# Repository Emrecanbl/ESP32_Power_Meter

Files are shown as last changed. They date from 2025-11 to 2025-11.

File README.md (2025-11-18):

# ESP32-S3 Power Meter (INA3221 ·  TFT · Qt Ui · SQLlite data base)

An ESP32-S3–based **three-channel power meter** built around INA3221. One channel supports **USB-C pass-through** so you can measure power flowing from **USB-C IN → USB-C OUT**; **CC pins are tied** for basic PD trigger behavior (power-only path).

> Firmware stack: **FreeRTOS**.
> REST/WebSocket API is **optional** (may be added later).
> Live data can be streamed over **USB-CDC**; an **optional ST7735 (160×128) SPI TFT** can show basic status (no touch).
>
> A custom **3D-printed enclosure** is planned.

---

---

## Features

* **3 measurement channels** via **INA3221**

  * Voltage (V), Current (A), Power (W), accumulated **mAh / mWh**
* **ESP32-S3** (Wi‑Fi + native USB/CDC)

  * UART header and USB device available on the board
* **USB‑C pass‑through (1 channel)**: measure power across IN → OUT

  * **CC lines tied** (basic PD role trigger; data lines not routed)
* **Optional TFT:** **ST7735 (160×128) SPI** for basic on-device status (no touch)
* **Battery**: **TP4056** Li‑ion charger + **AMS1117‑3.3** LDO
* **Enclosure**: custom **3D‑printed** case (to be published)

---

## What’s New

* Qt UI with Python and SQLite database integration

* Added boot-time Check screen: verifies Wi‑Fi link and sensor health before entering the UI.

* Check screen now shows connection status and the assigned IP address.

* Main screen updated to display the device IP for quick access to the Web UI.

* **ST7735 (160×128) screen added (no touch).**

* Energy counter buttons are active (Start/Stop/Reset)

* Sensor → UART JSON and Web UI hooked up

* 4-task FreeRTOS skeleton: sensor, screen, web, uart

## Gallery

<p align="center">
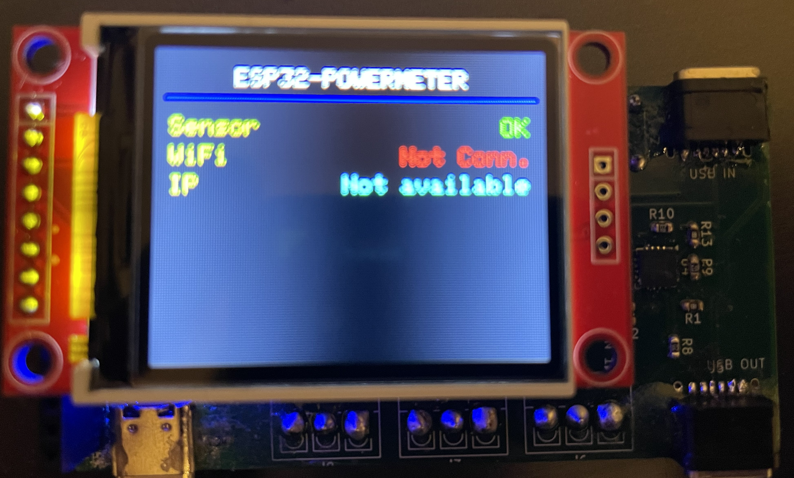
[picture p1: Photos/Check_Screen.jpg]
  &nbsp;&nbsp;
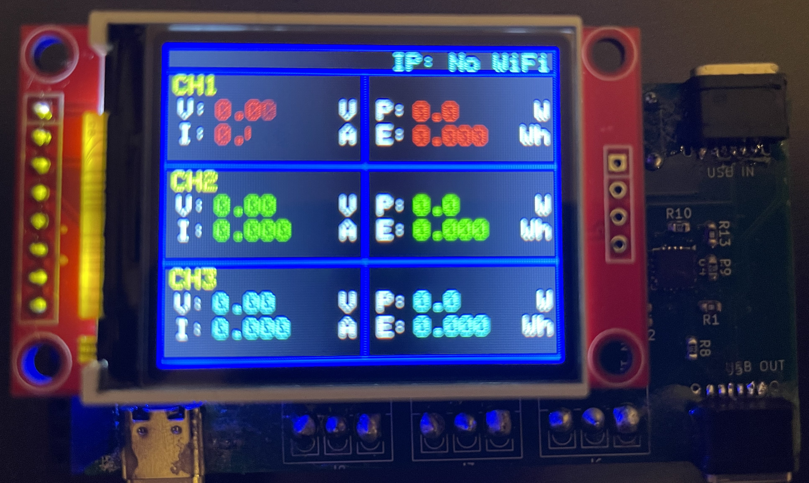
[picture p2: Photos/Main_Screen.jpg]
  <br>
  <em> First Check Screen &nbsp; | &nbsp; Main Screen </em>
</p>

<p align="center">
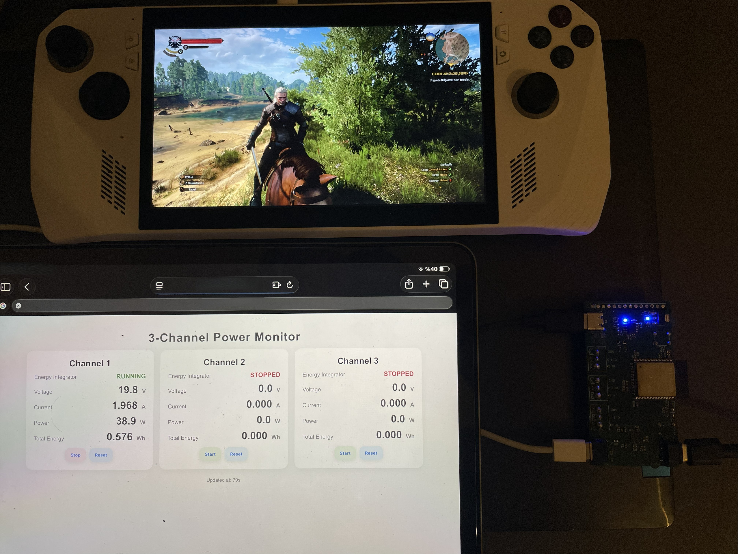
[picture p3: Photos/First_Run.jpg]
  &nbsp;&nbsp;
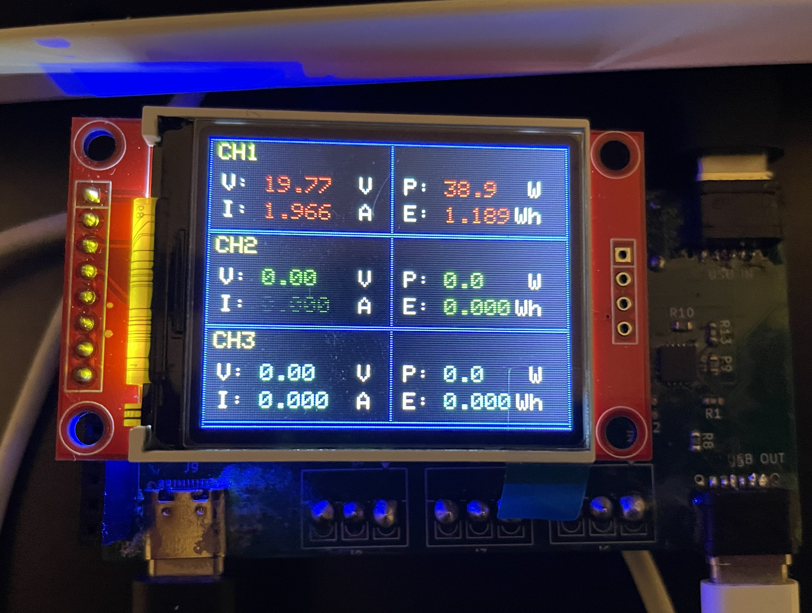
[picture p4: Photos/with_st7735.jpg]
  <br>
  <em> First Run Without Screen &nbsp; | &nbsp; With ST7735</em>
</p>

<p align="center">
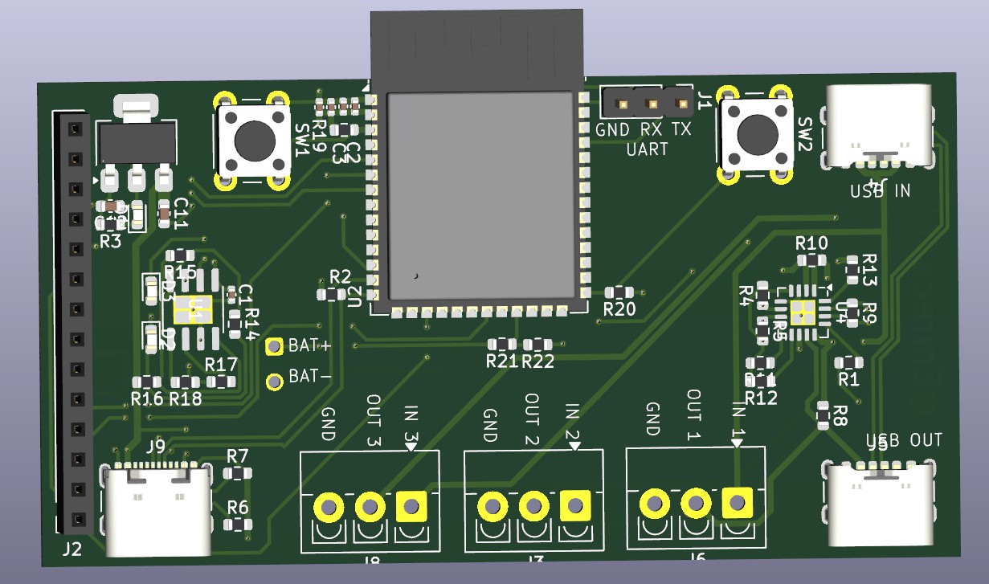
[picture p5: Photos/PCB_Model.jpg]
  &nbsp;&nbsp;
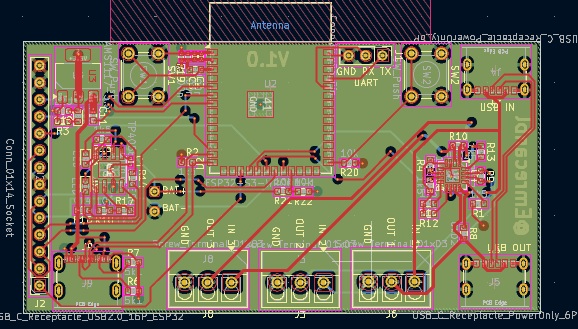
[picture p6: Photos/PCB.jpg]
  <br>
  <em>3D board render &nbsp; | &nbsp; PCB layout</em>
</p>

<p align="center">
  <!-- Add your prototype photos below when ready -->
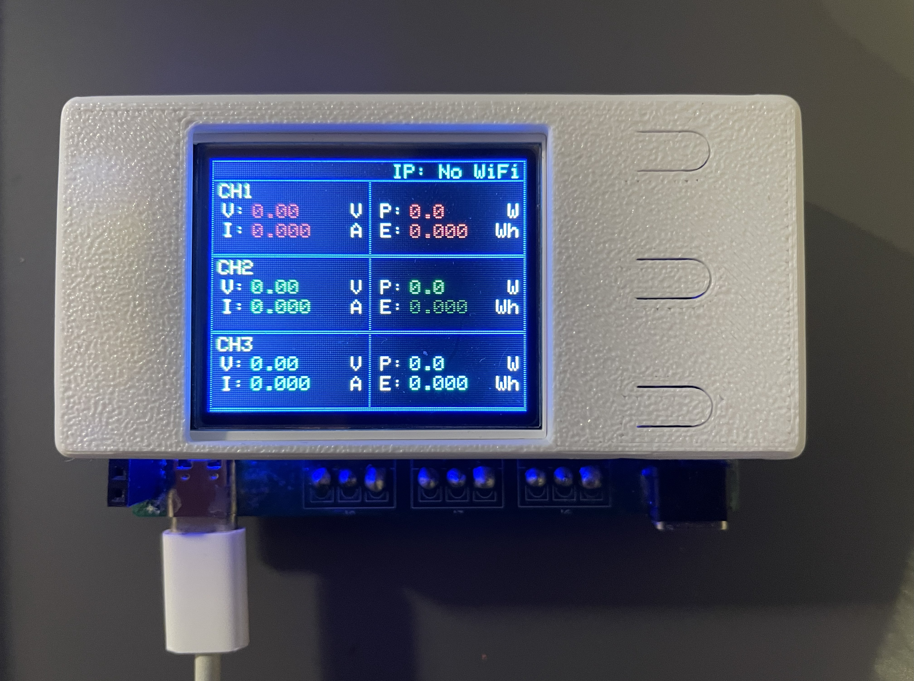
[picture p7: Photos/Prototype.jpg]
  &nbsp;&nbsp;
  <em>Prototype (front) </em>
</p>

<p align="center">
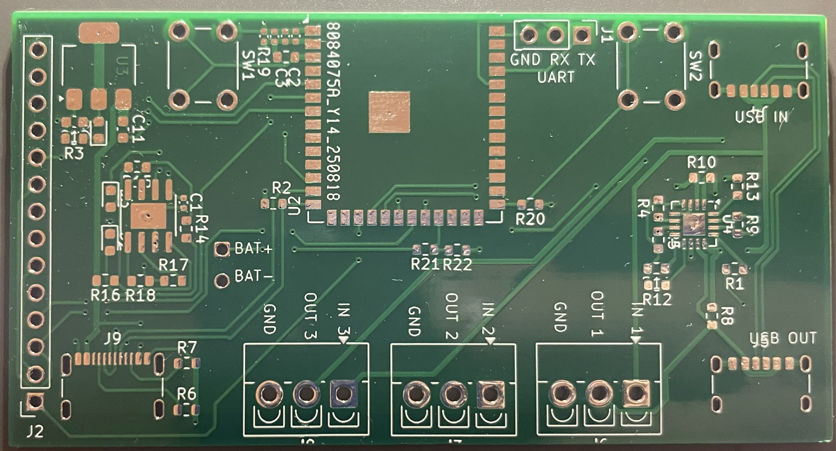
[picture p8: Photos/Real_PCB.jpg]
  <br>
  <em>Producted PCB (first article)</em>
</p>

<p align="center">
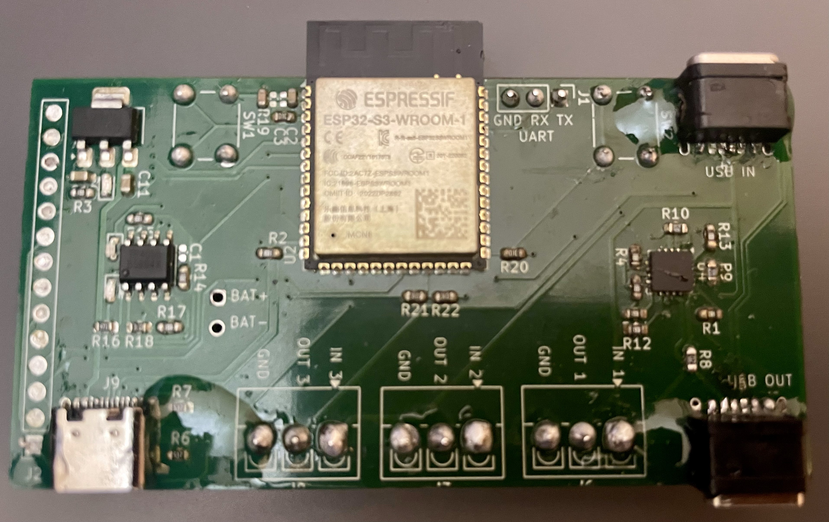
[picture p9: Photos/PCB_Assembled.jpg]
  <br>
  <em>Assembled PCB </em>
</p>

<p align="center">
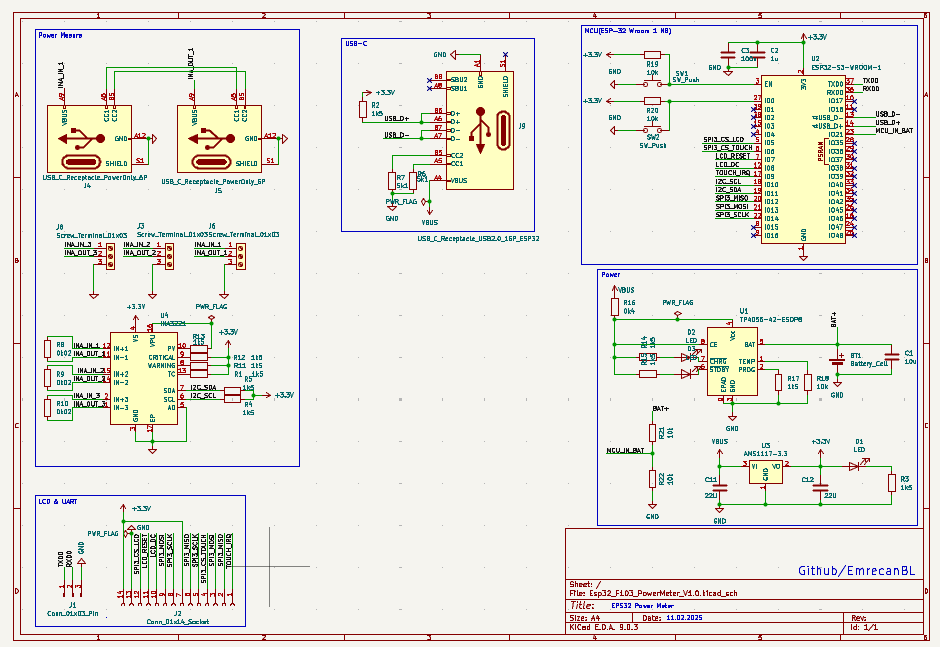
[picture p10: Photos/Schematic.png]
  <br>
  <em>Schematic (block view)</em>
</p>

<p align="center">
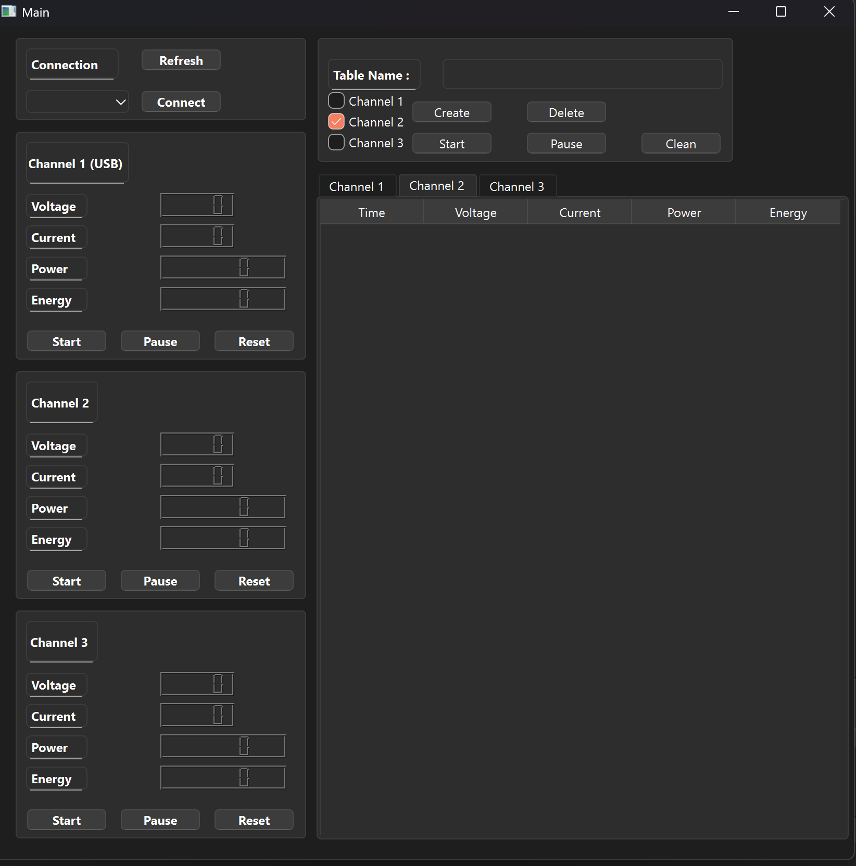
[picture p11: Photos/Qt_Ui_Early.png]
  <br>
  <em> Qt Ui </em>
</p>

## Hardware Overview

* **MCU:** ESP32‑S3 module
* **Power Monitor:** INA3221 (three shunts)
* **Optional Display:** ST7735 (160×128) over SPI (no touch)
* **Power Path:** USB‑C IN, USB‑C OUT (pass‑through on Channel 1)
* **PMICs:** TP4056 Li‑ion charger, AMS1117‑3.3 regulator
* **Connectors:** 3× screw terminals (IN/OUT/GND), UART header, 2× USB‑C

### Block Diagram

```
USB-C IN ──┐                  ┌── USB-C OUT (pass-through)
           ├─ Shunt CH1  ─────┤
IN/OUT CH2 ├─ Shunt CH2  ─────┤──> Loads
IN/OUT CH3 ├─ Shunt CH3  ─────┘
           │
        INA3221  ── I2C ── ESP32-S3 ── SPI ── ST7735 TFT (optional)
                               ├─ (Optional) Wi‑Fi HTTP/WS
                               └─ USB‑CDC / UART (streaming)
```

---

## Default Pins

| Function | ESP32‑S3 Pin |
| --- | --- |
| I2C SDA / SCL (INA3221) | GPIO __ / __ |
| TFT (ST7735) MOSI / MISO / SCK | GPIO __ / __ / __ |
| TFT CS / DC / RST | GPIO __ / __ / __ |
| UART RX / TX | GPIO __ / __ |
| USB‑CDC | Native (S3) |

---

## Firmware (planned)

* **Framework:** FreeRTOS
* **Modules:**

  * `sensor` – INA3221 sampling, filtering, mAh/mWh accumulation
  * `ui` *(optional)* – minimal status pages on **ST7735**; device can run headless
  * *(Optional)* `web` – HTTP + WebSocket for live JSON
  * `usb_stream` – ASCII/JSON streaming over USB‑CDC (no file logging)
* **Example JSON (USB/Web, if enabled):**

```json
{"ch":1,"voltage":5.08,"current":1.12,"power":5.69,"mah_total":23.4,"mwh_total":118.9,"ts":1730529652}
```

---

### Efficiency Measurement

The board can measure real conversion efficiency by comparing input and output power:

* Channels: CH1 = input (P_in), CH2 = output (P_out)
* Instantaneous: η_inst = P_out / P_in
* Averaged (stable): EMA over 1–3 s → η_avg =  P̄_out / P̄_in
* Energy-based: η_energy = ΔmWh_out / ΔmWh_in (robust against short spikes)

## Repo Layout (suggested)

```
/hardware
  schematic.pdf
  gerber/
/firmware
  /main
    board.h
    app_sensor.c
    app_ui_tft.c
    app_usb_stream.c
    (optional) app_web.c
  sdkconfig.defaults
/Photos
  PCB.jpg
  PCB_Model.jpg
  Prototype.jpg
  Prototype_Back1.jpg
  Prototype_Back2.jpg
  Real_PCB.jpg
  Schematic.png
/enclosure
  stl/  (3D-printed case files)
```

---

## Roadmap

* [ ] Bring‑up: INA3221 I2C readout
* [ ] Publish 3D‑printed enclosure (STL)
* [ ] USB‑CDC live streaming (no on‑device logs)
* [ ] Minimal on-device status (ST7735)
* [ ] Calibration UI + NVS storage
* [ ] (Optional) REST/WS endpoints

---

## Notes & Safety

* USB‑C pass‑through is **power‑only** (data lines not connected).
* CC lines support **basic PD trigger behavior**; PD profile support is **limited**.
* Verify shunt resistor wattage and temperature rise.
* Provide adequate thermal copper for **TP4056** during charging.

---

## License

MIT (to be added).

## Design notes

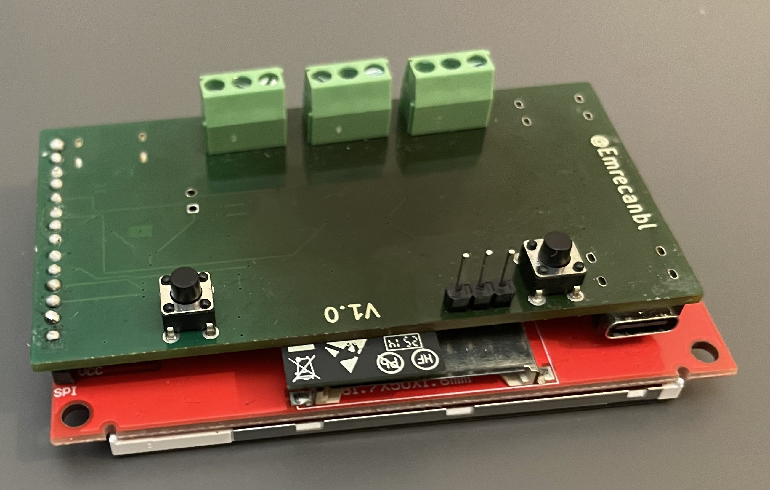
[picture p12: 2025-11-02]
Photos/Prototype_Back1.jpg

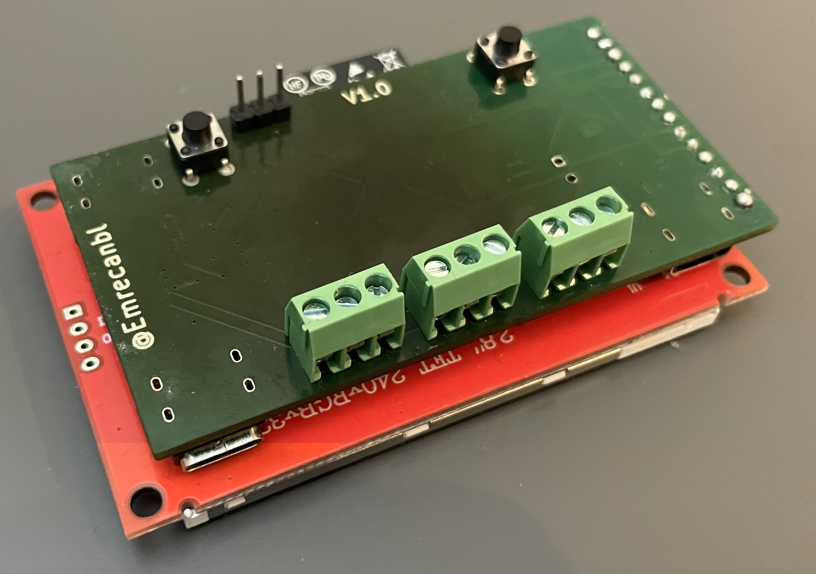
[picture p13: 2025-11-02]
Photos/Prototype_Back2.jpg

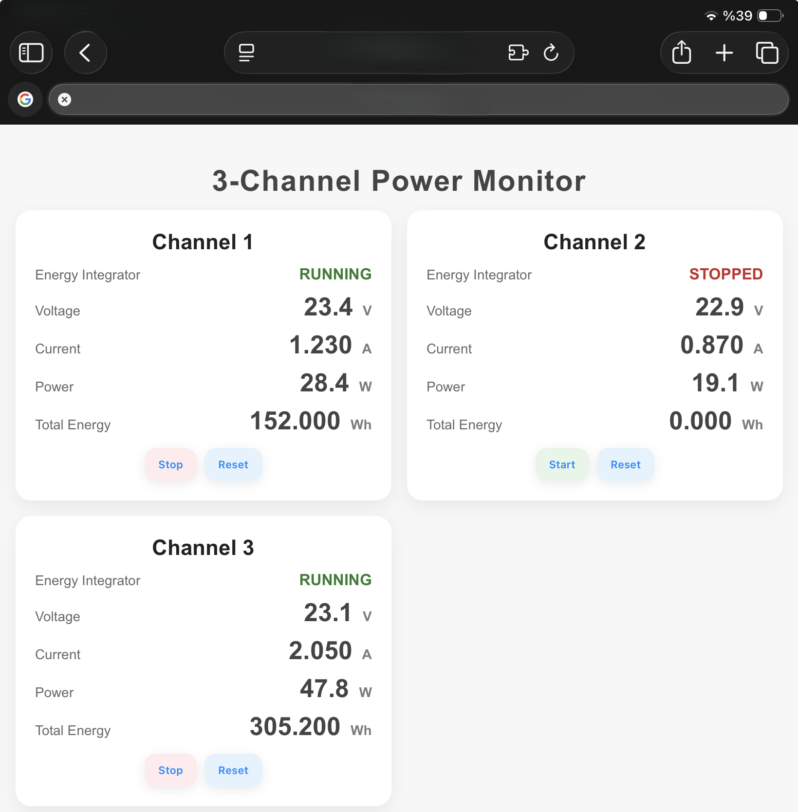
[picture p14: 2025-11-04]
Photos/WEBUI.png

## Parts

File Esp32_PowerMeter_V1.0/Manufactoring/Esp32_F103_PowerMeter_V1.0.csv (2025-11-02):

Reference | Qty | Value | DNP | Exclude from BOM | Exclude from Board | Footprint | Datasheet
BT1 | 1 | Battery_Cell |  |  |  | Connector_Molex:Molex_Micro-Fit_3.0_43045-0212_2x01_P3.00mm_Vertical | ~
C1 | 1 | 10u |  |  |  | Capacitor_SMD:C_0402_1005Metric | ~
C2 | 1 | 1u |  |  |  | Capacitor_SMD:C_0402_1005Metric | ~
C3 | 1 | 100n |  |  |  | Capacitor_SMD:C_0402_1005Metric | ~
C11,C12 | 2 | 22U |  |  |  | Capacitor_SMD:C_0603_1608Metric | ~
D1,D2,D3 | 3 | LED |  |  |  | LED_SMD:LED_0603_1608Metric | ~
J1 | 1 | Conn_01x03_Pin |  |  |  | Connector_PinHeader_2.54mm:PinHeader_1x03_P2.54mm_Vertical | ~
J2 | 1 | Conn_01x14_Socket |  |  |  | Connector_PinSocket_2.54mm:PinSocket_1x14_P2.54mm_Vertical | ~
J3,J6,J8 | 3 | Screw_Terminal_01x03 |  |  |  | TerminalBlock_4Ucon:TerminalBlock_4Ucon_1x03_P3.50mm_Vertical | ~
J4,J5 | 2 | USB_C_Receptacle_PowerOnly_6P |  |  |  | Connector_USB:USB_C_Receptacle_GCT_USB4125-xx-x_6P_TopMnt_Horizontal | https://www.usb.org/sites/default/files/documents/usb_type-c.zip
J9 | 1 | USB_C_Receptacle_USB2.0_16P_ESP32 |  |  |  | Connector_USB:USB_C_Receptacle_GCT_USB4105-xx-A_16P_TopMnt_Horizontal | https://www.usb.org/sites/default/files/documents/usb_type-c.zip
R1,R2,R3,R4,R5,R11,R12,R13,R14,R15,R17 | 11 | 1k5 |  |  |  | Resistor_SMD:R_0603_1608Metric | ~
R6,R7 | 2 | 5k1 |  |  |  | Resistor_SMD:R_0603_1608Metric | ~
R8,R9,R10 | 3 | 0k02 |  |  |  | Resistor_SMD:R_0603_1608Metric | ~
R16 | 1 | 0k4 |  |  |  | Resistor_SMD:R_0603_1608Metric | ~
R18,R19,R20,R21,R22 | 5 | 10k |  |  |  | Resistor_SMD:R_0603_1608Metric | ~
SW1,SW2 | 2 | SW_Push |  |  |  | Button_Switch_THT:SW_PUSH_6mm_H4.3mm | ~
U1 | 1 | TP4056-42-ESOP8 |  |  |  | Package_SO:SOIC-8-1EP_3.9x4.9mm_P1.27mm_EP2.41x3.3mm_ThermalVias | https://www.lcsc.com/datasheet/lcsc_datasheet_2410121619_TOPPOWER-Nanjing-Extension-Microelectronics-TP4056-42-ESOP8_C16581.pdf
U2 | 1 | ESP32-S3-WROOM-1 |  |  |  | RF_Module:ESP32-S3-WROOM-1 | https://www.espressif.com/sites/default/files/documentation/esp32-s3-wroom-1_wroom-1u_datasheet_en.pdf
U3 | 1 | AMS1117-3.3 |  |  |  | Package_TO_SOT_SMD:SOT-223-3_TabPin2 | http://www.advanced-monolithic.com/pdf/ds1117.pdf
U4 | 1 | INA3221 |  |  |  | Package_DFN_QFN:Texas_RGV0016A_VQFN-16-1EP_4x4mm_P0.65mm_EP2.1x2.1mm | http://www.ti.com/lit/ds/symlink/ina3221.pdf

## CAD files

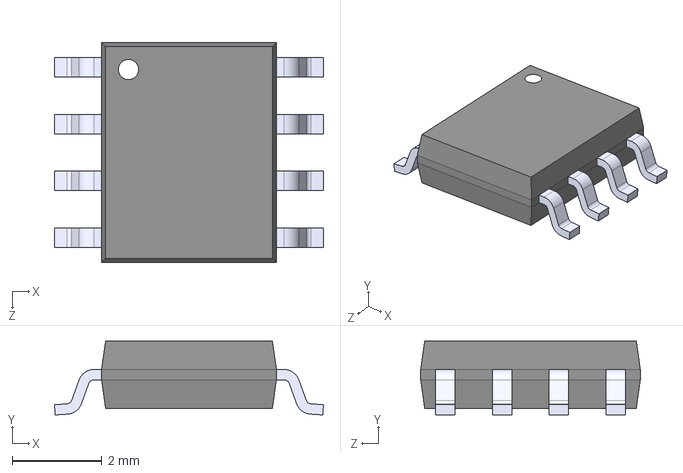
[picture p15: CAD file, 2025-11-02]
Esp32_PowerMeter_V1.0/IP5306.step
6.00 x 1.65 x 4.90 mm

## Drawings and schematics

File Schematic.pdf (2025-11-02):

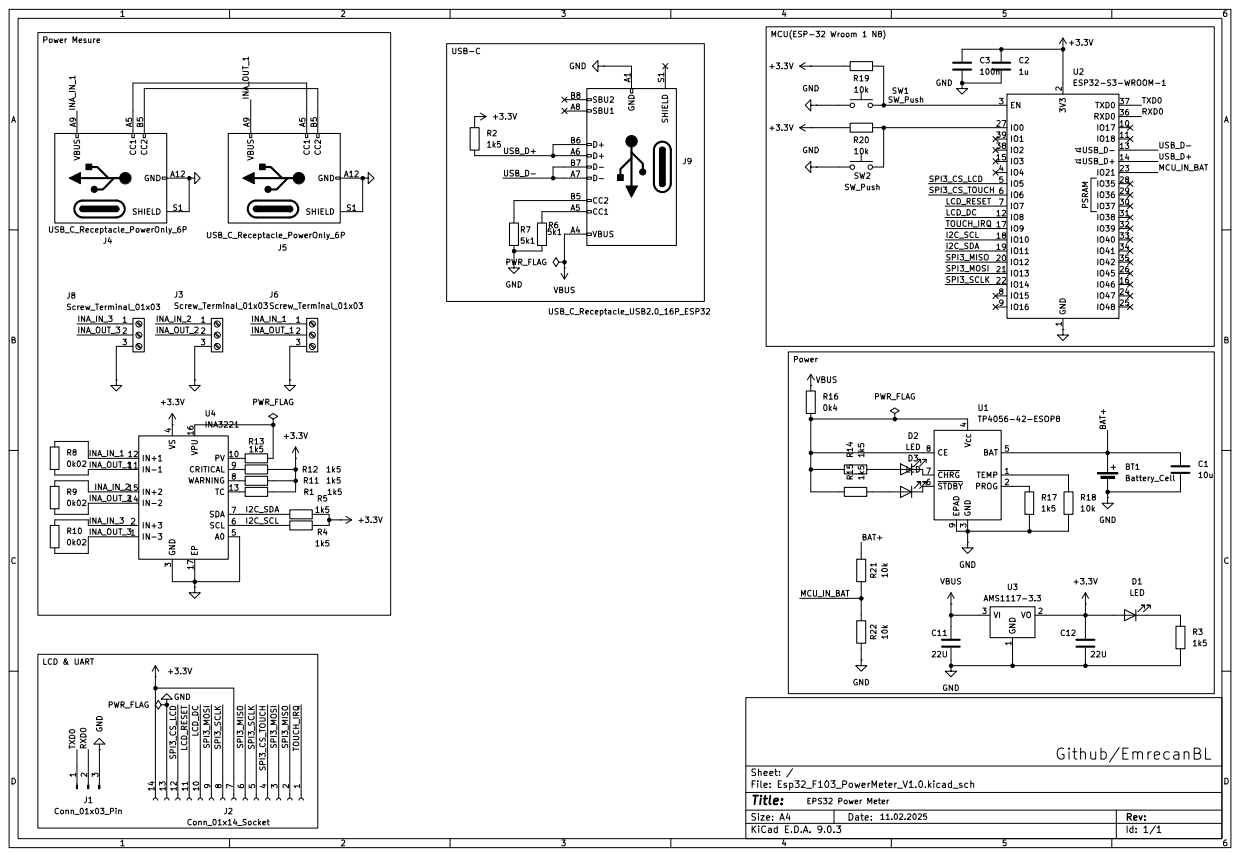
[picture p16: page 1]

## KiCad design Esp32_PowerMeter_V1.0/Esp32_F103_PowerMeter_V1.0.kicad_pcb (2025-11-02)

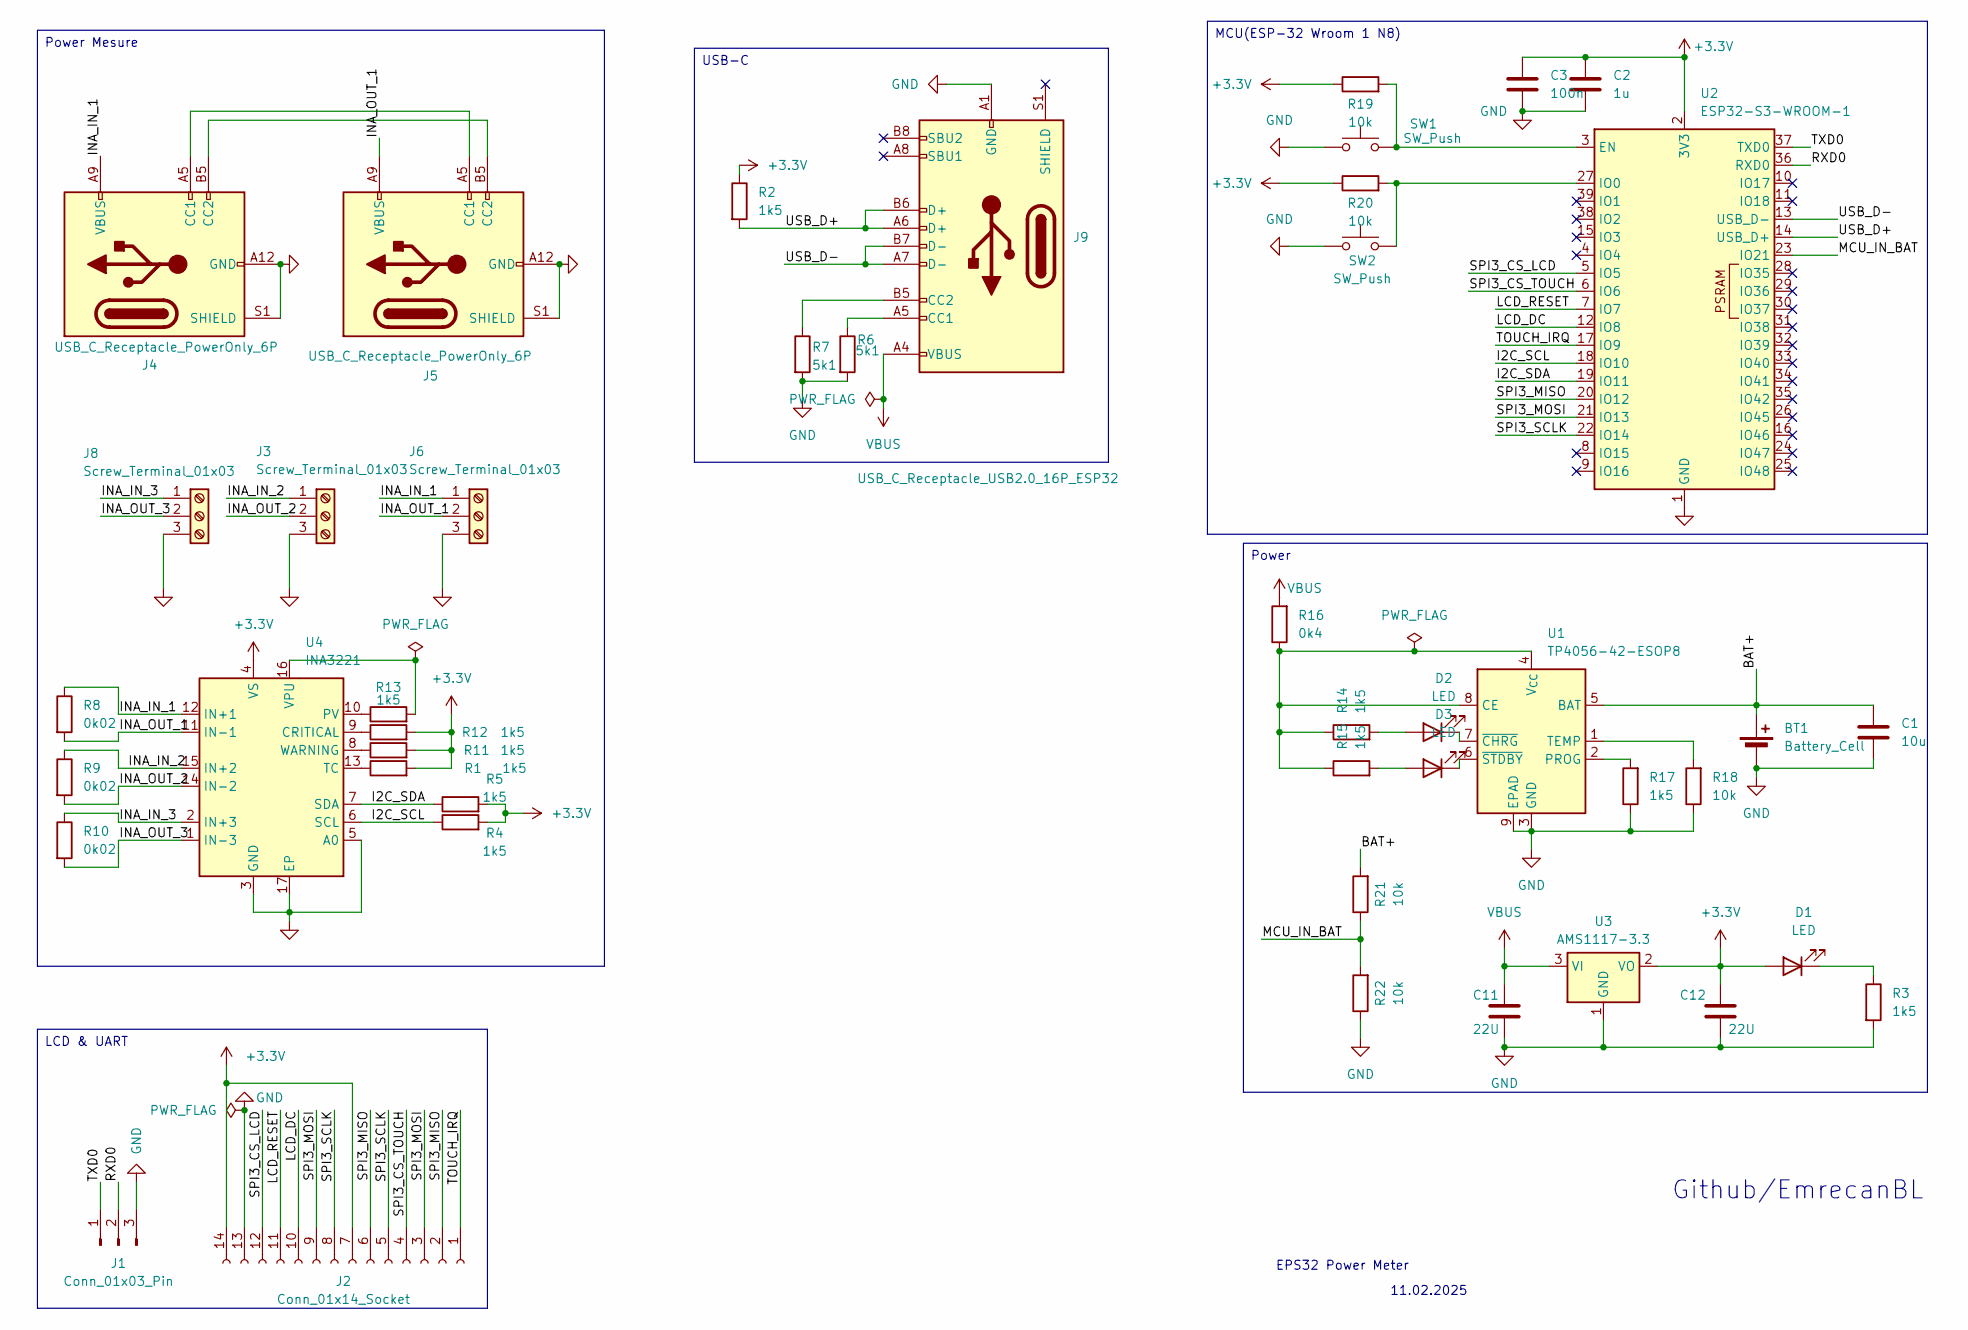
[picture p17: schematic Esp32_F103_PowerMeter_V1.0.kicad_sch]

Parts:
BT1: Battery_Cell; Molex_Micro-Fit_3.0_43045-0212_2x01_P3.00mm_Vertical
C1: 10u; C_0402_1005Metric
C2: 1u; C_0402_1005Metric
C3: 100n; C_0402_1005Metric
C11, C12: 22U; C_0603_1608Metric
D1, D2, D3: LED; LED_0603_1608Metric
J1: Conn_01x03_Pin; PinHeader_1x03_P2.54mm_Vertical
J2: Conn_01x14_Socket; PinSocket_1x14_P2.54mm_Vertical
J3, J6, J8: Screw_Terminal_01x03; TerminalBlock_4Ucon_1x03_P3.50mm_Vertical
J4, J5: USB_C_Receptacle_PowerOnly_6P; USB_C_Receptacle_GCT_USB4125-xx-x_6P_TopMnt_Horizontal
J9: USB_C_Receptacle_USB2.0_16P_ESP32; USB_C_Receptacle_GCT_USB4105-xx-A_16P_TopMnt_Horizontal
R1, R2, R3, R4, R5, R11, R12, R13, R14, R15, R17: 1k5; R_0603_1608Metric
R6, R7: 5k1; R_0603_1608Metric
R8, R9, R10: 0k02; R_0603_1608Metric
R16: 0k4; R_0603_1608Metric
R18, R19, R20, R21, R22: 10k; R_0603_1608Metric
SW1, SW2: SW_Push; SW_PUSH_6mm_H4.3mm
U1: TP4056-42-ESOP8; SOIC-8-1EP_3.9x4.9mm_P1.27mm_EP2.41x3.3mm_ThermalVias
U2: ESP32-S3-WROOM-1
U3: AMS1117-3.3; SOT-223-3_TabPin2
U4: INA3221; Texas_RGV0016A_VQFN-16-1EP_4x4mm_P0.65mm_EP2.1x2.1mm

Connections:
+3.3V: C2.1, C3.1, C12.1, D1.2 (A), J2.7, J2.14, R1.2, R2.1, R4.2, R5.2, R11.2, R12.2, R19.1, R20.1, U2.2 (3V3), U3.2 (VO), U4.4 (VS); also elsewhere on the board
/BAT+: BT1.1 (+), C1.1, R21.2, U1.5 (BAT)
/I2C_SCL: R4.1, U2.18 (IO10), U4.6 (SCL)
/I2C_SDA: R5.1, U2.19 (IO11), U4.7 (SDA)
/INA_IN_1: J4.A9 (VBUS), J4.B9 (VBUS), J6.1, R8.1, U4.12 (IN+1)
/INA_IN_2: J3.1, R9.1, U4.15 (IN+2)
/INA_IN_3: J8.1, R10.1, U4.2 (IN+3)
/INA_OUT_1: J5.A9 (VBUS), J5.B9 (VBUS), J6.2, R8.2, U4.11 (IN-1)
/INA_OUT_2: J3.2, R9.2, U4.14 (IN-2)
/INA_OUT_3: J8.2, R10.2, U4.1 (IN-3)
/LCD_DC: J2.10, U2.12 (IO8)
/LCD_RESET: J2.11, U2.7 (IO7)
/MCU_IN_BAT: R21.1, R22.2, U2.23 (IO21)
/RXD0: J1.2, U2.36 (RXD0)
/SPI3_CS_LCD: J2.12, U2.5 (IO5)
/SPI3_CS_TOUCH: J2.4, U2.6 (IO6)
/SPI3_MISO: J2.2, J2.6, U2.20 (IO12)
/SPI3_MOSI: J2.3, J2.9, U2.21 (IO13)
/SPI3_SCLK: J2.5, J2.8, U2.22 (IO14)
/TOUCH_IRQ: J2.1, U2.17 (IO9)
/TXD0: J1.1, U2.37 (TXD0)
/USB_D+: J9.A6 (D+), J9.B6 (D+), R2.2, U2.14 (USB_D+)
/USB_D-: J9.A7 (D-), J9.B7 (D-), U2.13 (USB_D-)
GND: BT1.2 (-), C1.2, C2.2, C3.2, C11.2, C12.2, J1.3, J2.13, J3.3, J4.A12 (GND), J4.B12 (GND), J4.S1 (SHIELD), J5.A12 (GND), J5.B12 (GND), J5.S1 (SHIELD), J6.3, J8.3, J9.A1 (GND), J9.A12 (GND), J9.B1 (GND), J9.B12 (GND), R3.2, R6.2, R7.2, R17.1, R18.1, R22.1, SW1.1, SW2.1, U1.3 (GND), U1.9 (EPAD), U2.1 (GND), U2.40 (GND), U2.41 (GND), U3.1 (GND), U4.3 (GND), U4.5 (A0), U4.17 (EP); also elsewhere on the board
unnamed: D1.1 (K), R3.1
unnamed: D2.2 (A), R14.2
unnamed: D2.1 (K), U1.7 (~CHRG)
unnamed: D3.2 (A), R15.2
unnamed: D3.1 (K), U1.6 (~STDBY)
unnamed: J4.A5 (CC1), J5.A5 (CC1)
unnamed: J4.B5 (CC2), J5.B5 (CC2)
unnamed: J9.A5 (CC1), R6.1
unnamed: J9.B5 (CC2), R7.1
unnamed: R14.1, R15.1, R16.1, U1.4 (V_{CC}), U1.8 (CE)
unnamed: R17.2, U1.2 (PROG)
unnamed: R18.2, U1.1 (TEMP)
unnamed: R19.2, SW1.2, U2.3 (EN)
unnamed: R20.2, SW2.2, U2.27 (IO0)
unnamed: R12.1, U4.9 (CRITICAL)
unnamed: R13.1, U4.10 (PV)
unnamed: R1.1, U4.13 (TC)
unnamed: R13.2, U4.16 (VPU)
unnamed: R11.1, U4.8 (WARNING)
VBUS: C11.1, J9.A4 (VBUS), J9.A9 (VBUS), J9.B4 (VBUS), J9.B9 (VBUS), R16.2, U3.3 (VI)

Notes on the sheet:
11.02.2025
Github/EmrecanBL
EPS32 Power Meter
USB-C
LCD & UART
Power
MCU(ESP-32 Wroom 1 N8)
Power Mesure

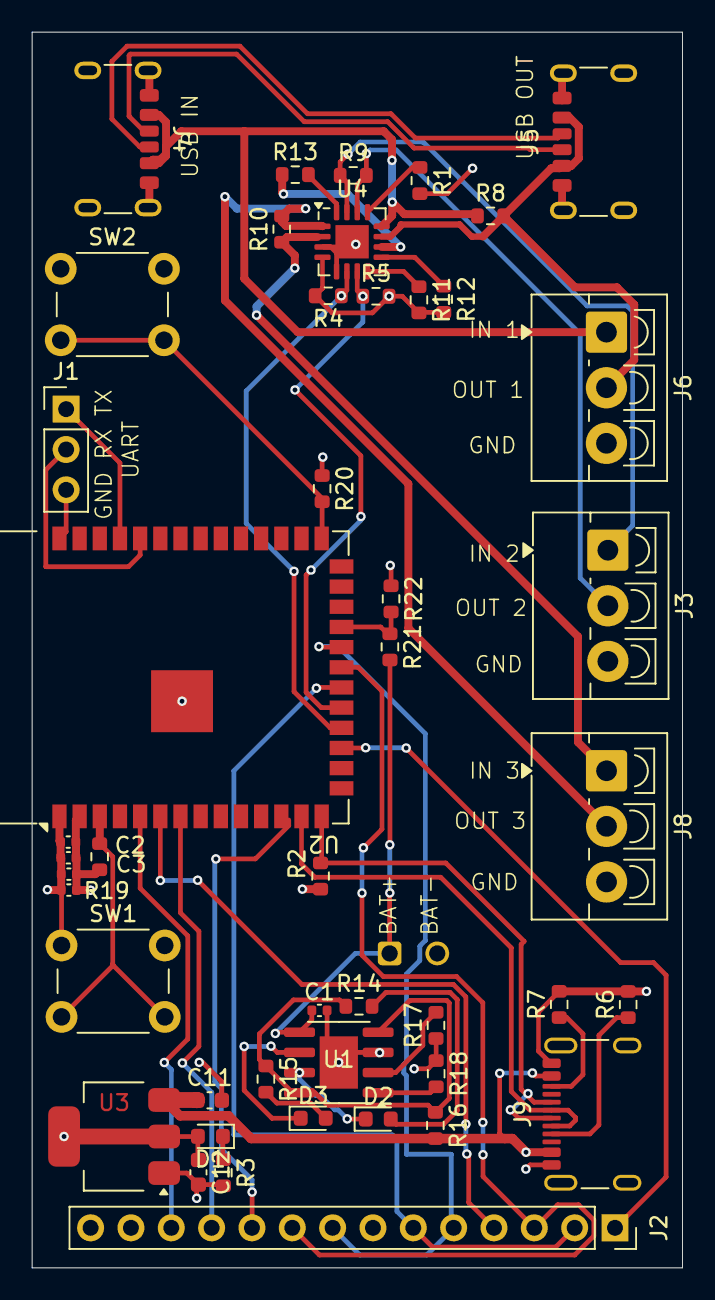
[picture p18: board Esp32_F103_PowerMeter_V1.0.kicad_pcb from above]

Board: 4 copper layers, 41.0 x 77.8 mm, 47 parts (0 on the bottom side), 44 nets.

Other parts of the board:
C2#2: 1u; C_0402_1005Metric
C3#2: 100n; C_0402_1005Metric

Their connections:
+3.3V: C2#2.1, C3#2.1; also elsewhere on the board
GND: C2#2.2, C3#2.2; also elsewhere on the board

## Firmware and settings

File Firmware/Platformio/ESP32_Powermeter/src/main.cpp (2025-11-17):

#include <main.h>

PowerSample power_Values;

// ---- Sync primitives ----
static SemaphoreHandle_t g_Sensor_read_Mutex = nullptr; // protects Sensor_read and Uart_out

// --- Tasks (empty bodies) ---
static void taskSensor(void* arg) {
  (void)arg;
  for (;;) {
    if (xSemaphoreTake(g_Sensor_read_Mutex, 100) == pdTRUE){
    Sensor_Read(power_Values);
    xSemaphoreGive(g_Sensor_read_Mutex);
    vTaskDelay(pdMS_TO_TICKS(SENSOR_PERIOD_MS));
  }
  }
}


static void taskScreen(void* arg) {
  (void)arg;
  for (;;) {
    if (xSemaphoreTake(g_Sensor_read_Mutex, 100) == pdTRUE){
      TFT_UpdateValues(power_Values);
      xSemaphoreGive(g_Sensor_read_Mutex);
    }
    vTaskDelay(pdMS_TO_TICKS(SCREEN_PERIOD_MS));
  }
}


static void taskWeb(void* arg) {
  (void)arg;
  for (;;) {
    if (xSemaphoreTake(g_Sensor_read_Mutex, 1000) == pdTRUE){
      WEB_UI_Stream(power_Values);
      xSemaphoreGive(g_Sensor_read_Mutex);
    }
    vTaskDelay(pdMS_TO_TICKS(WEB_LOOP_MS));
  }
}


static void taskUart(void* arg) {
  (void)arg;
  for (;;) {
    if (xSemaphoreTake(g_Sensor_read_Mutex, 100) == pdTRUE){
      Sensor_Uart_Out(power_Values);
      xSemaphoreGive(g_Sensor_read_Mutex);
    }
    vTaskDelay(pdMS_TO_TICKS(UART_PERIOD_MS));
  }
}


// --- Setup: only creates tasks ---
void setup() {
Serial.begin(115200);
Sensor_init();
WEB_UI_init();
LCD_ST7735_init();
g_Sensor_read_Mutex = xSemaphoreCreateMutex();
// Create tasks (adjust stack/prio/cores)
xTaskCreatePinnedToCore(taskSensor, "sensor", 4096, nullptr, 3, nullptr, 1);
xTaskCreatePinnedToCore(taskScreen, "screen", 4096, nullptr, 2, nullptr, 1);
xTaskCreatePinnedToCore(taskUart, "uart", 4096, nullptr, 1, nullptr, 0);
xTaskCreatePinnedToCore(taskWeb, "web", 4096, nullptr, 2, nullptr, 0);

g_buttonQueue = xQueueCreate(6, sizeof(ButtonEvent));
pinMode(BUTTON_PINS[0], INPUT_PULLUP);
pinMode(BUTTON_PINS[1], INPUT_PULLUP);
pinMode(BUTTON_PINS[2], INPUT_PULLUP);

attachInterrupt(digitalPinToInterrupt(BUTTON_PINS[0]), button0ISR, FALLING);
attachInterrupt(digitalPinToInterrupt(BUTTON_PINS[1]), button1ISR, FALLING);
attachInterrupt(digitalPinToInterrupt(BUTTON_PINS[2]), button2ISR, FALLING);
}


void loop() {
  vTaskDelay(pdMS_TO_TICKS(1000));
}


static void IRAM_ATTR handleButtonFromISR(uint8_t index) {
  const bool isLow = digitalRead(BUTTON_PINS[index]) == LOW;
  BaseType_t hpTaskWoken = pdFALSE;
  const TickType_t now = xTaskGetTickCountFromISR();

  if (isLow && !g_buttonStates[index].pressed) {
    g_buttonStates[index].pressed = true;
    g_buttonStates[index].pressTick = now;
  } else if (!isLow && g_buttonStates[index].pressed) {
    const TickType_t delta = now - g_buttonStates[index].pressTick;
    const bool isLong = delta >= LONG_PRESS_TICKS;
    ButtonEvent evt{index, isLong};
    g_buttonStates[index].pressed = false;
    xQueueSendFromISR(g_buttonQueue, &evt, &hpTaskWoken);
  }
  if (hpTaskWoken == pdTRUE) {
    portYIELD_FROM_ISR();
  }
}

static void IRAM_ATTR button0ISR() { handleButtonFromISR(0); }
static void IRAM_ATTR button1ISR() { handleButtonFromISR(1); }
static void IRAM_ATTR button2ISR() { handleButtonFromISR(2); }


static void taskButtons(void* arg) {
  ButtonEvent evt;
  for (;;) {
    if (xQueueReceive(g_buttonQueue, &evt, portMAX_DELAY) == pdPASS) {
      if (evt.longPress) {
        power_Values.reset_state[evt.index] = !power_Values.reset_state[evt.index]; 
      }
      else {
        power_Values.counter_state[evt.index] = !power_Values.counter_state[evt.index];
      }
    }
  }
}

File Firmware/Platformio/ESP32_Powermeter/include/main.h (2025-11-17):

#include <Arduino.h>
#include <INA3221.h>
#include <Web_Ui.h>
#include <LCD_ST7735.h>
#include <esp_system.h>
// ---------- Config ----------
static constexpr uint32_t SENSOR_PERIOD_MS = 100; // 10 Hz
static constexpr uint32_t SCREEN_PERIOD_MS = 8; // ~30 FPS (adjust as needed)
static constexpr uint32_t UART_PERIOD_MS = 1000; // 1 Hz
static constexpr uint32_t WEB_LOOP_MS = 10; // service HTTP frequently
static constexpr uint32_t Mutex_Max_Wait_MS = 1000;                 

struct Start_Check
{
 bool Sensor_Started = false;
 bool Wifi_Connected = false;
 String Wifi_ip;
};

extern Start_Check Check;

constexpr uint8_t BUTTON_PINS[3] = {6, 9, 15};      // adjust to your wiring
constexpr TickType_t LONG_PRESS_TICKS = pdMS_TO_TICKS(1500);
constexpr TickType_t ISR_QUEUE_TIMEOUT = 0;

static void IRAM_ATTR button0ISR();
static void IRAM_ATTR button1ISR();
static void IRAM_ATTR button2ISR();

struct ButtonEvent {
  uint8_t index;
  bool longPress;
};

struct ButtonState {
  TickType_t pressTick = 0;
  bool pressed = false;
};

static ButtonState g_buttonStates[3];
static QueueHandle_t g_buttonQueue;
static SemaphoreHandle_t g_buttonMux = xSemaphoreCreateBinary();
static bool g_isRunning = false;

void initButtons();
static void toggleRunState();
static void taskButtons(void* arg);
static void toggleResetState() ;

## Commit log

2025-11-02 Project Created
    [Esp32_F103_PowerMeter_V1.0-B_Cu.gbr, Esp32_F103_PowerMeter_V1.0-B_Mask.gbr, Esp32_F103_PowerMeter_V1.0-B_Paste.gbr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]
2025-11-03 PCB_Assambled
    PCB foto update
2025-11-03 PCB_Assembled
    PCB Assembled Photo
2025-11-04 Firmware first version
    Sensor, WEB Ui and Uart Integrated
2025-11-05 Wifi and Sensor check
